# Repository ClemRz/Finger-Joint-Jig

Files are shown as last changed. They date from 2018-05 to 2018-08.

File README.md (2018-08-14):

# Finger-Joint-Jig

This is the software and electronic-hardware design of my finger joint jig

## How to use it

Plug the jig to the power source

### How to access the virtual UI

 1. With you smart-phone, tablet, computer, etc. connect to the wifi signal named `WiFingerJointJig`, no password needed.
 2. Open a browser and go to [http://192.168.4.1](http://192.168.4.1)
 3. The setings page should load by itself
 4. Change the values and push submit, the page should reload and the jig is ready to be used

### How to use the physical UI

There are 3 buttons:

  - Left (Next): move the jig to the next cutting spot
  - Center (Un/Lock): toggle the lock "pressure" implied by the stepper
  - Right (Previous): move the jig back to the last known position

2 LEDs allows you to know what's going on:

  - Red LED: either the carriage is in movement or it is unlocked (center button)
  - Green LED: the carriage is static and locked in place

When the settings are sent to the device (via the virtual UI) the LEDs blink as a confirmation.

## Software design

There are 3 main elements in this design:

  - A quadruple H-bridge (L293D) in charge of driving the stepper.
  - An Arduino Pro Mini (5V, 16MHz) in charge of the movement logic. It is connected by I2C as a slave to the ESP.
  - An ESP8266 in charge of serving the virtual UI and keeping the settings in EEPROM. This is the master in the I2C network.
 
The ESP and Arduino firmwares are quite self explanatory. You will be able to get the `ino` files at the root of this repo.

The HTML UI is embedded inside the ESP's firmware but you can modify it following those simple steps:

 1. Install `npm` and `grunt` (documentation: [https://gruntjs.com/](https://gruntjs.com/))
 2. Install the dependencies, run in a terminal at the root of the project: `nom install`
 3. Modify client.html as you wish.
 4. Run `grunt` in the same terminal.
 5. Copy the content of `generated/client.html` to `server.ino#sendWebPage`
 6. Save and upload your fimware to the ESP. `Rx`, `Tx` and `GND` are exposed via male headers as well as a programing rocker switch.
 
## Hardware design
 
I used [Fritzing](http://fritzing.org) to draw the electronic diagram (see breadboard below).

And [SketchUp](https://www.sketchup.com/) to draw the mechanic parts (see in the screenshot section).

## Feel free

If you want to reproduce, modify or enhance my variation of this jig, feel free to do it respecting the licence enclosed in this repo.

If you detect a bug or a possible enhancement to the code, feel free to send me a merge request, open an issue or leave a comment!

Thanks!

## Screenshots

 Demonstration: https://youtu.be/sLcKFr8kczg
 
 Virtual UI:
 
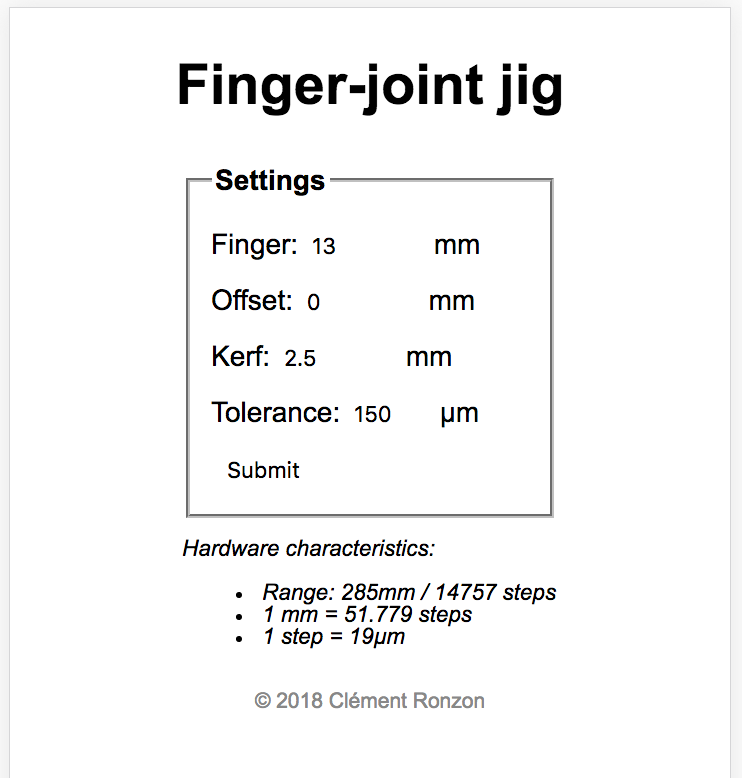
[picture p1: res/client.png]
 
 
 Electronic design:
 
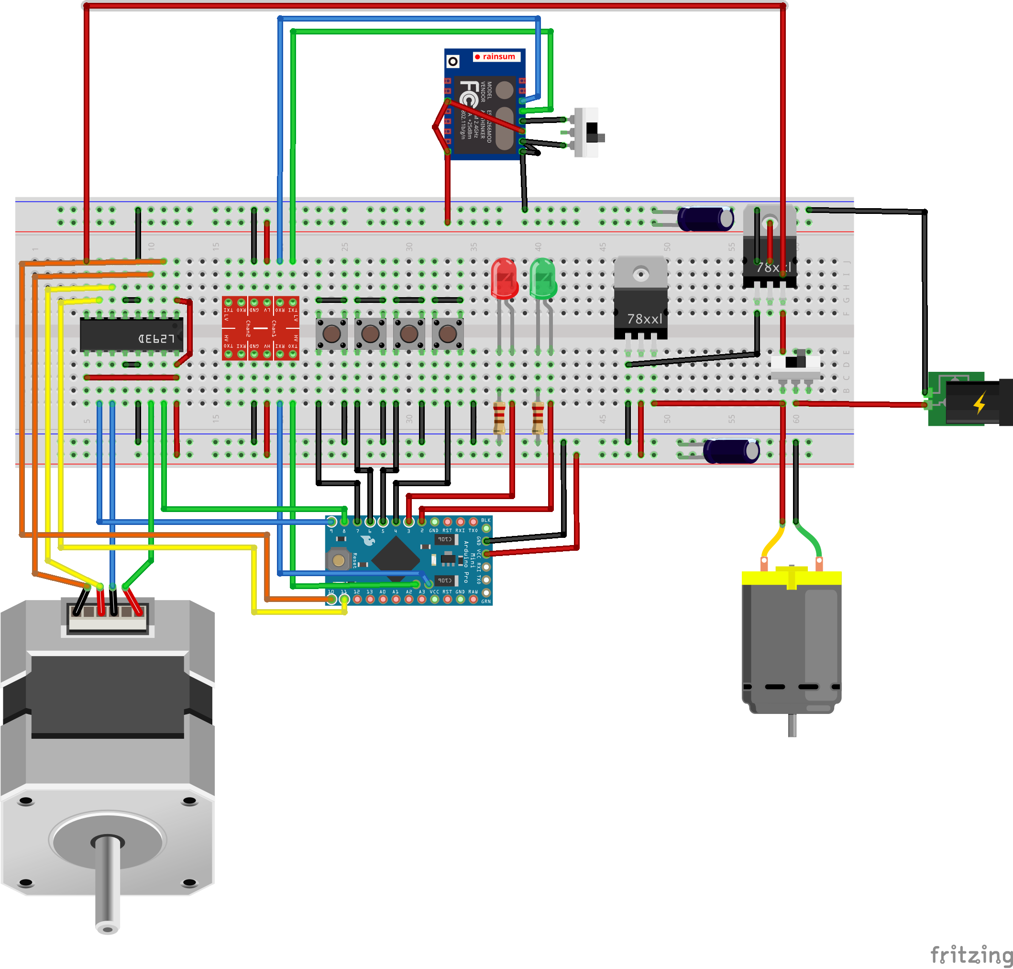
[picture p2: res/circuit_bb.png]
Circuit
 

 Mechanic desing:
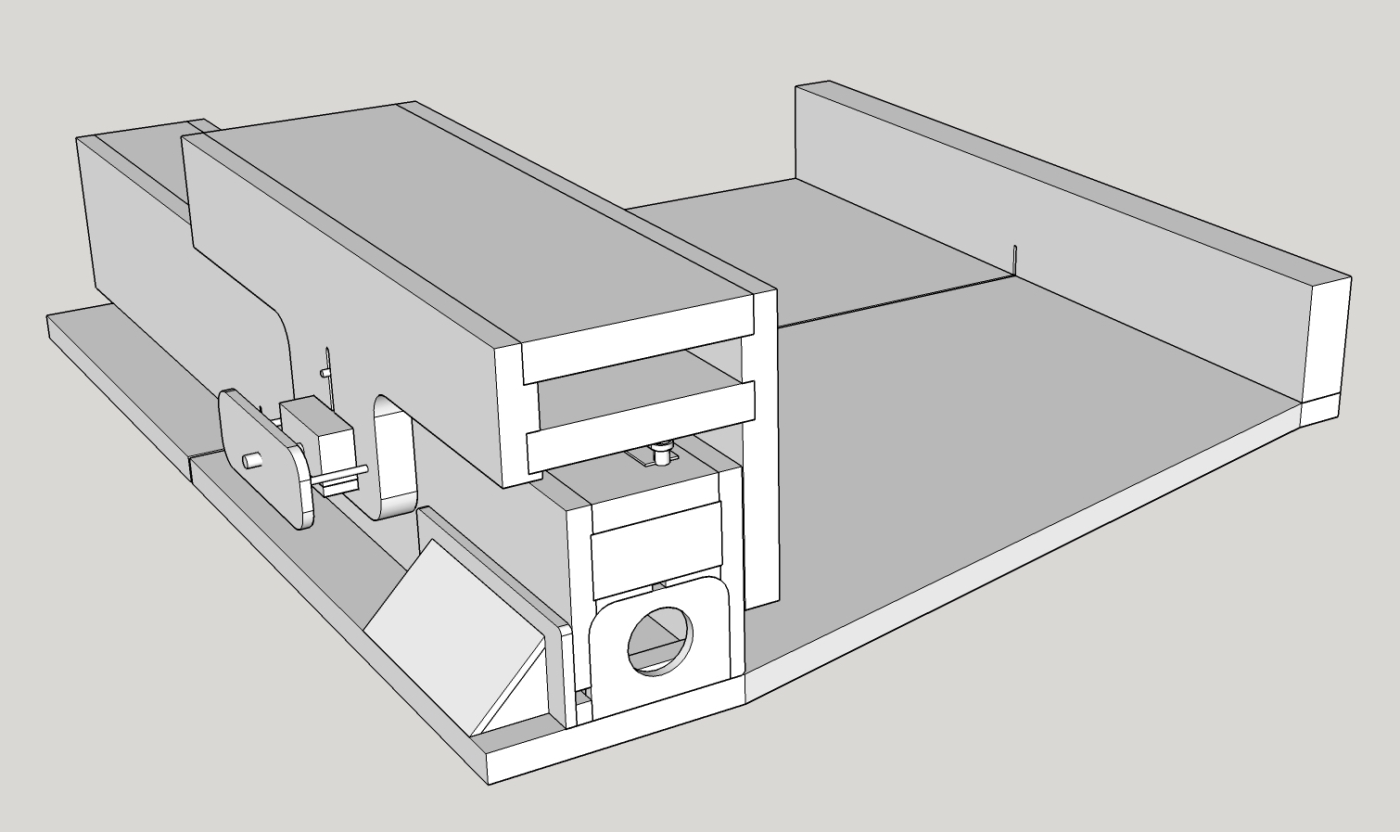
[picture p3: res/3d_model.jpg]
Model


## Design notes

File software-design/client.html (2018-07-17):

# Finger-joint jig

Settings Finger: mm
Offset: mm
Kerf: mm
Tolerance: µm

Hardware characteristics:

- Range: 307mm / 14757 steps
- 1 mm = 48.068 steps
- 1 step = 21µm

© 2018 Clément Ronzon

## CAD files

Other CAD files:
hardware-design/finger joint jig.skp

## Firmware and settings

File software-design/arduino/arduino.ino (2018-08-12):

/**
Copyright (c) 2018, Clément Ronzon
All rights reserved.

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
* Neither the name of current-data-logger nor the names of its
  contributors may be used to endorse or promote products derived from
  this software without specific prior written permission.

THIS SOFTWARE IS PROVIDED BY THE COPYRIGHT HOLDERS AND CONTRIBUTORS "AS IS"
AND ANY EXPRESS OR IMPLIED WARRANTIES, INCLUDING, BUT NOT LIMITED TO, THE
IMPLIED WARRANTIES OF MERCHANTABILITY AND FITNESS FOR A PARTICULAR PURPOSE ARE
DISCLAIMED. IN NO EVENT SHALL THE COPYRIGHT HOLDER OR CONTRIBUTORS BE LIABLE
FOR ANY DIRECT, INDIRECT, INCIDENTAL, SPECIAL, EXEMPLARY, OR CONSEQUENTIAL
DAMAGES (INCLUDING, BUT NOT LIMITED TO, PROCUREMENT OF SUBSTITUTE GOODS OR
SERVICES; LOSS OF USE, DATA, OR PROFITS; OR BUSINESS INTERRUPTION) HOWEVER
CAUSED AND ON ANY THEORY OF LIABILITY, WHETHER IN CONTRACT, STRICT LIABILITY,
OR TORT (INCLUDING NEGLIGENCE OR OTHERWISE) ARISING IN ANY WAY OUT OF THE USE
OF THIS SOFTWARE, EVEN IF ADVISED OF THE POSSIBILITY OF SUCH DAMAGE.
 */

#include <Wire.h>                   // https://github.com/esp8266/Arduino/
#include <AccelStepper.h>           // http://www.airspayce.com/mikem/arduino/AccelStepper/index.html
#include <LinkedList.h>             // https://github.com/ivanseidel/LinkedList
#include "register.h"               // https://github.com/ClemRz/Introduction-to-IoT#use-structures

// Stepper settings
#define RANGE_IN_MM         307.0                         // mm
#define RANGE_IN_STEPS      14757.0                       // steps
#define STEPS_PER_MM        (RANGE_IN_STEPS/RANGE_IN_MM)  // setps/mm (51.779 steps/mm)
#define MM_PER_STEP         (RANGE_IN_MM/RANGE_IN_STEPS)  // mm/step (0.019 mm/step)
#define FULL_SPEED          1800                          // steps/s (34.763 mm/s)
#define LOW_SPEED           150                           // steps/s (2.897 mm/s)
#define FULL_ACC            4000                          // steps/s2 (77.251 mm/s2)
#define LOW_ACC             200                           // steps/s2 (3.863 mm/s2)

// i2c settings
#define SLAVE_I2C_ADDRESS   0x09

// Pins
#define GREEN_LED           2
#define RED_LED             3
#define ENABLE_MOTOR        4
#define GO_PREV_STEP_BT     5
#define TOGGLE_MOTOR_BT     6
#define GO_NEXT_STEP_BT     7

// Buttons management
#define DEBOUNCE_DELAY_MS   500L

// Commands
#define NONE                0
#define NEXT_STEP           1
#define PREVIOUS_STEP       2
#define TOGGLING            3

// Globals
AccelStepper stepper(AccelStepper::HALF4WIRE, 8, 9, 10, 11, ENABLE_MOTOR);
uint8_t _operation =        NONE;
unsigned long
  _lastButtonTime =         0;
bool _motorIsEnabled =      true;

// Volatiles
volatile Register _v_register;

LinkedList<long> _indexes = LinkedList<long>();

void setup(void) {
  Serial.begin(115200);
  Serial.println();
  defaultRegister();
  initLed();
  showBusy();
  initI2c();
  initButtons();
  printDefinition();
  printRegister();
  showReady();
}

void loop(void) {
  listenButtons();
  if (_operation != NONE) {
    showBusy();
    switch(_operation) {
      case NEXT_STEP:
        Serial.println(F("Next Step"));
        goToNextStep();
        break;
      case PREVIOUS_STEP:
        Serial.println(F("Previous Step"));
        goToPreviousStep();
        break;
      case TOGGLING:
        Serial.println(F("Toggle motor"));
        toggleMotor();
        break;
    }
    showReady();
    _operation = NONE;
  }
}

void defaultRegister(void) {
  _v_register.kerfMm = 2.09;
  _v_register.fingerMm = 6.0;
  _v_register.toleranceUm = 150.0;
  _v_register.offsetMm = 0.0;
}

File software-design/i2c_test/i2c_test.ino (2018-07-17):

#include <Wire.h>                   // https://github.com/esp8266/Arduino/
#include "register.h"               // https://github.com/ClemRz/Introduction-to-IoT#use-structures

// i2c settings
#define SLAVE_I2C_ADDRESS   0x09

Register _register;

void setup(void) {
  Serial.begin(115200);
  Serial.println();
  randomSeed(analogRead(0));
  initI2c();
  writeArduino();
}

void loop(void) {
}

void defaultRegister(void) {
  _register.kerfMm = random(0, 1000)/100.0;
  _register.fingerMm = 13.0;
  _register.toleranceUm = 150.0;
  _register.offsetMm = 0.0;
  Serial.println(_register.kerfMm);
}

void initI2c(void) {
  Wire.begin();
}

void writeArduino(void) {
  defaultRegister();
  Wire.beginTransmission(SLAVE_I2C_ADDRESS);
  Wire.write(_register.byteAt, REG_MAP_SIZE);
  Wire.endTransmission();
}

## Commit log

2018-04-27 Updates arduino
2018-05-06 Updates arduino fw
2018-05-06 Adds LEDs
2018-05-10 Fixes bug after manual testing
    [arduino.ino, buttons.ino, i2c.ino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]
2018-05-15 Changes register to use float instead of double. Double are not the same size in arduino and ESP. Fixes the config reading function.
    [ap.ino, arduino.ino, buttons.ino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]
2018-05-16 Adds back button. Adds Arduino initialization.
2018-05-16 Adds hardware design
    [circuit.fzz]
2018-05-16 Fixes the 'back' process.
    [esp8266.ino, stepManagement.ino]
2018-05-16 Fixes hardware design
    [circuit.fzz]
2018-06-06 Removes ISRs. Clears the history when homing.
2018-06-06 Updates hardware design
    [circuit.fzz]
2018-07-17 Removes homing and adds motor lock/unlock instead
2018-07-17 Adds I2C test - Arduino to Arduino
2018-08-12 Updates software and hardware
    [finger joint jig.skp]
2018-08-14 Adds some details about the LEDs in the readme
